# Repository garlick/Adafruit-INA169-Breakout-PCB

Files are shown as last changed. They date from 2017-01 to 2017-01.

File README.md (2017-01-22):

# Load switch and power measurement breakout

Breakout board containing TI TPS22958 DC load switch
and INA169 analog DC power measurement.  The target
load is the 5V supply of a Raspberry Pi version 3.

Uses 24-pin 600mil DIP form factor.

## forked from Adafruit-INA169-Breakout-PCB

PCB files for Adafruit INA169 Analog DC power measurement Breakout

Format is EagleCAD schematic and board layout

For more details, check out the product page at

  * https://www.adafruit.com/product/1164

Adafruit invests time and resources providing this open source design, 
please support Adafruit and open-source hardware by purchasing 
products from Adafruit!

Designed by Adafruit Industries.  
Creative Commons Attribution, Share-Alike license, check license.txt for more information
All text above must be included in any redistribution

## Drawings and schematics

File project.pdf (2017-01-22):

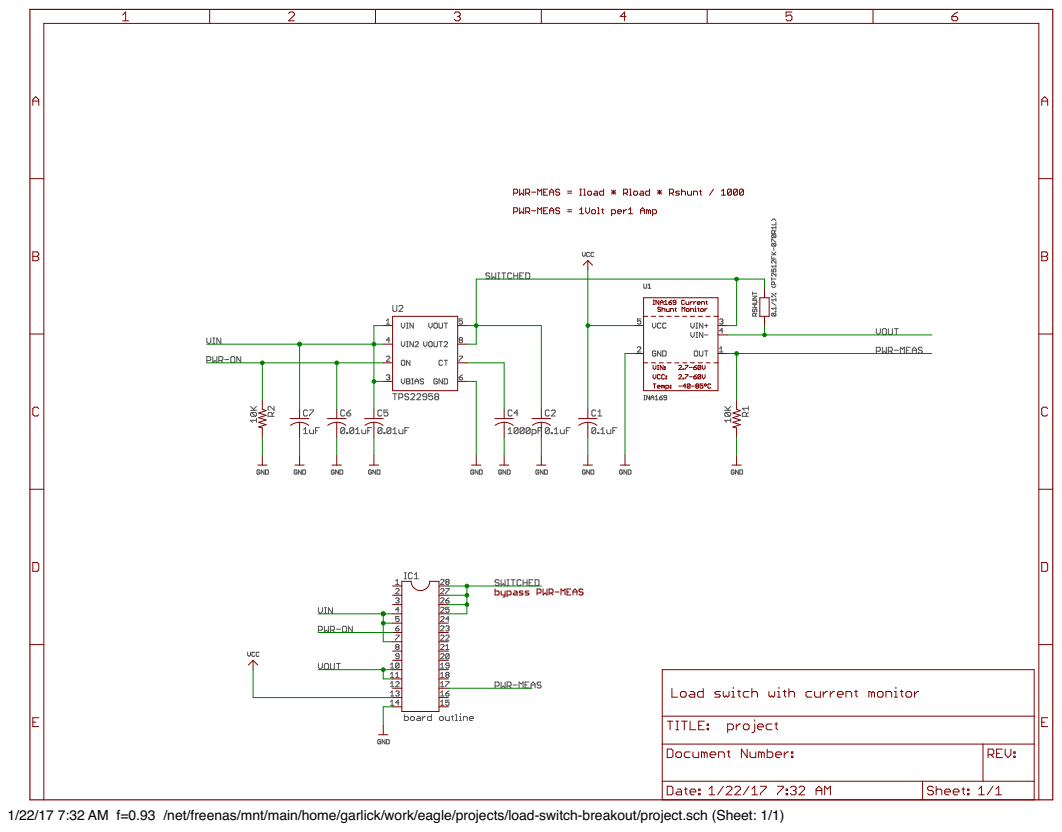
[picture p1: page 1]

1/22/17 7:32 AM f=0.93 /net/freenas/mnt/main/home/garlick/work/eagle/projects/load-switch-breakout/project.sch (Sheet: 1/1)

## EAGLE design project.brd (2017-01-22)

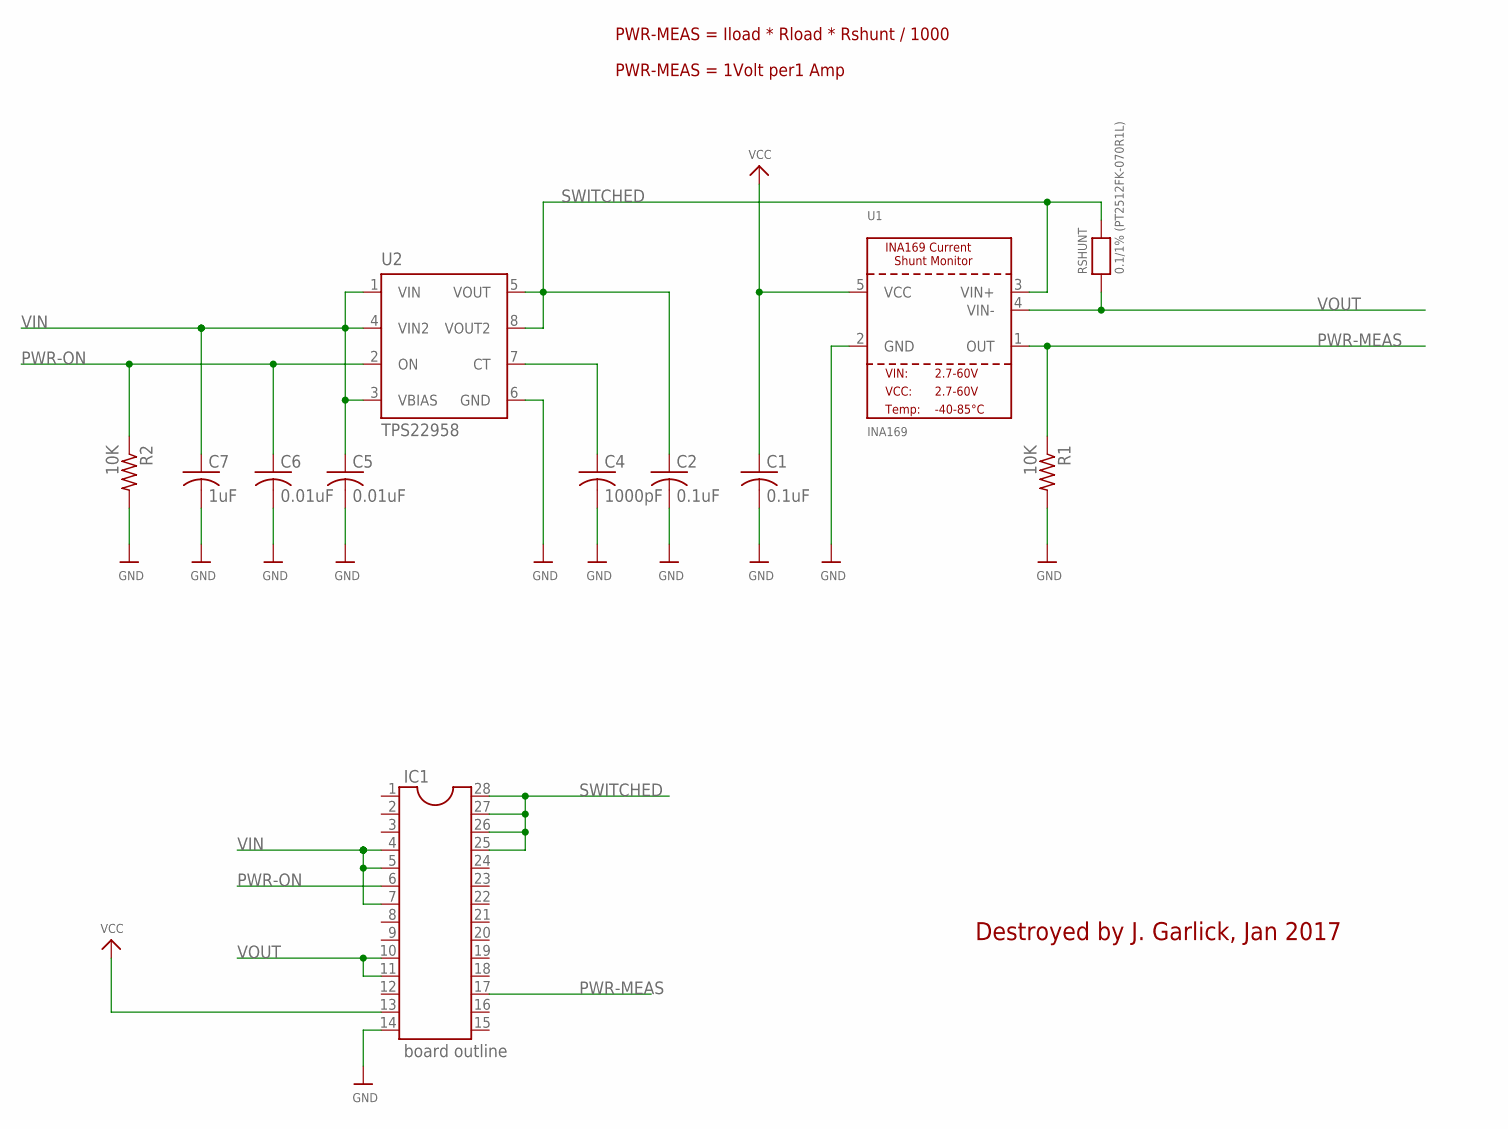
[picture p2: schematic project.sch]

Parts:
C1, C2: 0.1uF; C1206K
C4: 1000pF; C1206K
C5, C6: 0.01uF; C1206K
C7: 1uF; C1206K
IC1: board outline; DIL28-6
R1, R2: 10K; M1206
RSHUNT: 0.1/1% (PT2512FK-070R1L); 2512
U1: INA169; SOT23-5
U2: TPS22958; S-PDSO-G08

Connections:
CT: C4.1, U2.7 (CT)
GND: C1.2, C2.2, C4.2, C5.2, C6.2, C7.2, IC1.14, R1.2, R2.2, U1.2 (GND), U2.6 (GND)
PWR-MEAS: IC1.17, R1.1, U1.1 (OUT)
PWR-ON: C6.1, IC1.6, R2.1, U2.2 (ON)
SWITCHED: C2.1, IC1.25, IC1.26, IC1.27, IC1.28, RSHUNT.2, U1.3 (VIN+), U2.5 (VOUT), U2.8 (VOUT2)
VCC: C1.1, IC1.13, U1.5 (VCC)
VIN: C5.1, C7.1, IC1.4, IC1.5, IC1.7, U2.1 (VIN), U2.3 (VBIAS), U2.4 (VIN2)
VOUT: IC1.10, IC1.11, RSHUNT.1, U1.4 (VIN-)

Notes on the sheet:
PWR-MEAS = Iload * Rload * Rshunt / 1000
PWR-MEAS = 1Volt per1 Amp
Destroyed by J. Garlick, Jan 2017

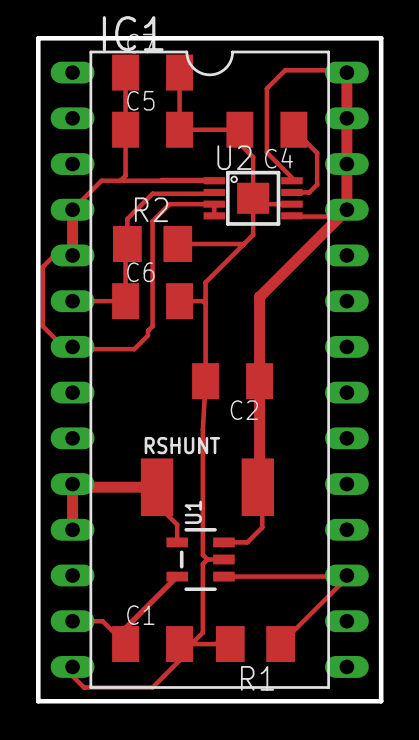
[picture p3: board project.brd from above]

Board: 2 copper layers, 19.1 x 36.8 mm, 12 parts (0 on the bottom side), 8 nets.

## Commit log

2017-01-16 add load switch and rework for 24p DIL 600mil outline
    [Adafruit INA169 CurPowerMonitor.brd, Adafruit INA169 CurPowerMonitor.sch]
2017-01-22 rename project files
    [project.brd, project.sch]
2017-01-22 Makefile: generate gerbers
2017-01-22 project.brd: add milling layer for board outline
    [project.brd]
2017-01-22 project.sch: replace frame with generic one
    [project.sch]
